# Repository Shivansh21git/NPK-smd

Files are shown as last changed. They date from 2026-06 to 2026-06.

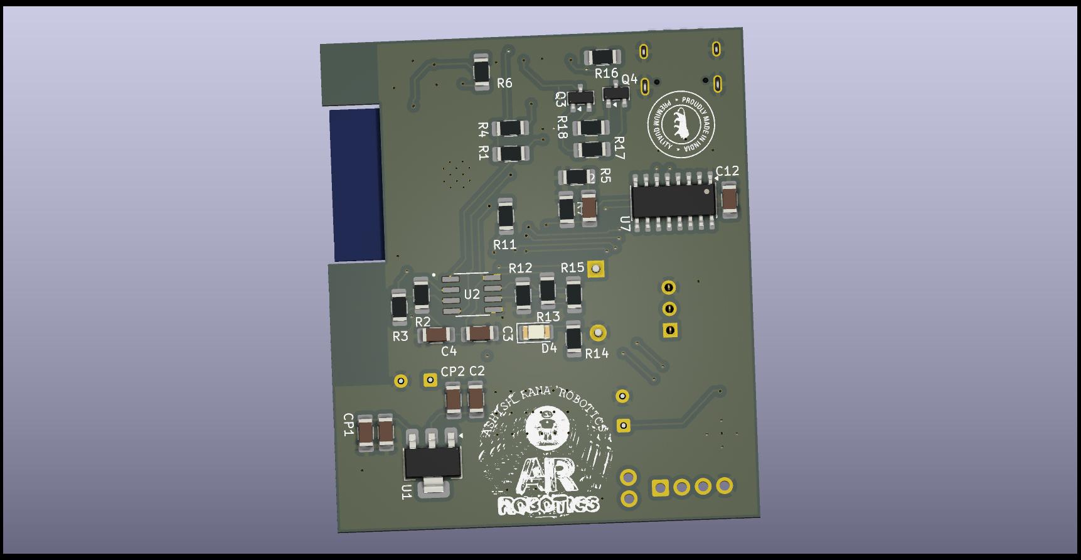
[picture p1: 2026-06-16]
images/NPK_smd_back.jpg

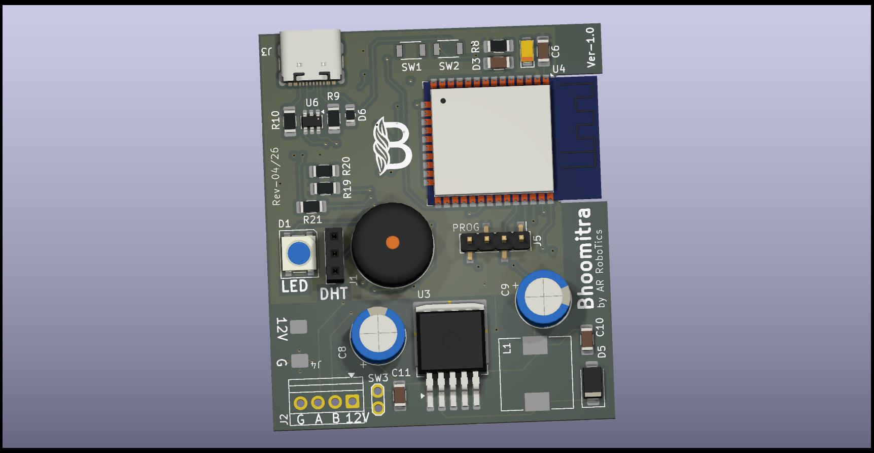
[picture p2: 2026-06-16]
images/NPK_smd_front.jpg

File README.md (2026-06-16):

# 🌱 Bhoomitra (Krishi Sarthi) – Smart NPK Soil Monitoring System

## 📌 Overview

**Bhoomitra (Krishi Sarthi)** is an embedded + IoT-based smart agriculture system designed to monitor **soil nutrient levels (NPK)** and assist farmers in making data-driven fertilization decisions.

The latest version introduces a **compact, optimized hardware architecture**, making the system more portable, robust, and suitable for real-world deployment in farms.

---

## 🎯 Problem Statement

Farmers often apply fertilizers based on guesswork, which leads to:

* Overuse of chemicals
* Increased cost
* Soil degradation
* Reduced crop yield

**Bhoomitra solves this by providing real-time soil nutrient insights.**

---

## 🧠 System Architecture

### 🔷 High-Level Architecture

```
Soil → NPK Sensor → Microcontroller → Data Processing → Output (Display / IoT)
```

### 🔷 Functional Blocks

1. **Sensing Layer**

   * NPK sensor measures Nitrogen, Phosphorus, Potassium
2. **Processing Layer**

   * Microcontroller processes raw sensor data
3. **Communication Layer (optional)**

   * Sends data to cloud / mobile app (if IoT enabled)
4. **Output Layer**

   * Displays readings or recommendations

---

## 🔌 Hardware Architecture

### 🧩 Components Used

* NPK Soil Sensor
* Microcontroller (Arduino / ESP32 / similar)
* Power Supply Module
* Display (LCD/OLED) or Serial Output
* Communication Module (WiFi / GSM – optional)

### ⚙️ Hardware Design Improvements

* ✅ Compact PCB / module layout
* ✅ Reduced wiring complexity
* ✅ Lower power consumption
* ✅ Field-ready enclosure design
* ✅ Improved durability for outdoor usage

### 🔄 Data Flow (Hardware)

1. Sensor probes inserted into soil
2. Sensor outputs analog/digital signals
3. Microcontroller reads signals via ADC/UART
4. Data is processed and calibrated
5. Output is displayed or transmitted

---

## 💻 Software Architecture

### 🧱 Software Layers

#### 1. Sensor Interface Layer

* Handles communication with NPK sensor
* Reads raw values (via UART / Analog pins)

#### 2. Data Processing Layer

* Calibration of sensor values
* Conversion into usable NPK units
* Filtering noise (basic smoothing if applied)

#### 3. Logic Layer

* Determines soil fertility status
* Can map values to:

  * Low / Medium / High nutrient levels
* Optional: fertilizer recommendation logic

#### 4. Output Layer

* Serial Monitor / LCD display
* IoT dashboard (if connected)

---

## 🔄 Working Principle

1. The NPK sensor is inserted into soil.
2. It measures nutrient concentration levels.
3. Microcontroller reads and processes the data.
4. Values are converted into meaningful units.
5. Output is shown to the user or transmitted.
6. Farmer uses insights for fertilizer planning.

---

## 🌐 IoT Integration (Optional)

* Real-time monitoring via cloud
* Data logging for analysis
* Remote farm monitoring
* Mobile-based access

---

## 📊 Example Use Case

* Farmer checks soil before sowing
* Detects low nitrogen level
* Applies only required fertilizer
* Saves cost and improves yield

---

## 🚀 Advantages

* 🌱 Promotes precision agriculture
* 💰 Reduces fertilizer waste
* 📈 Improves crop productivity
* 📦 Compact and portable design
* 🔧 Easy to deploy and maintain

---

## 🔮 Future Enhancements

* AI-based fertilizer recommendation
* Mobile app integration
* GPS-based soil mapping
* Multi-parameter sensing (pH, moisture, temperature)

---

## 📂 Repository Contents

* Embedded code
* Circuit design / hardware files
* Documentation

---

## 👨‍💻 Author

Shivansh
**Project:** Bhoomitra (Krishi Sarthi)

---

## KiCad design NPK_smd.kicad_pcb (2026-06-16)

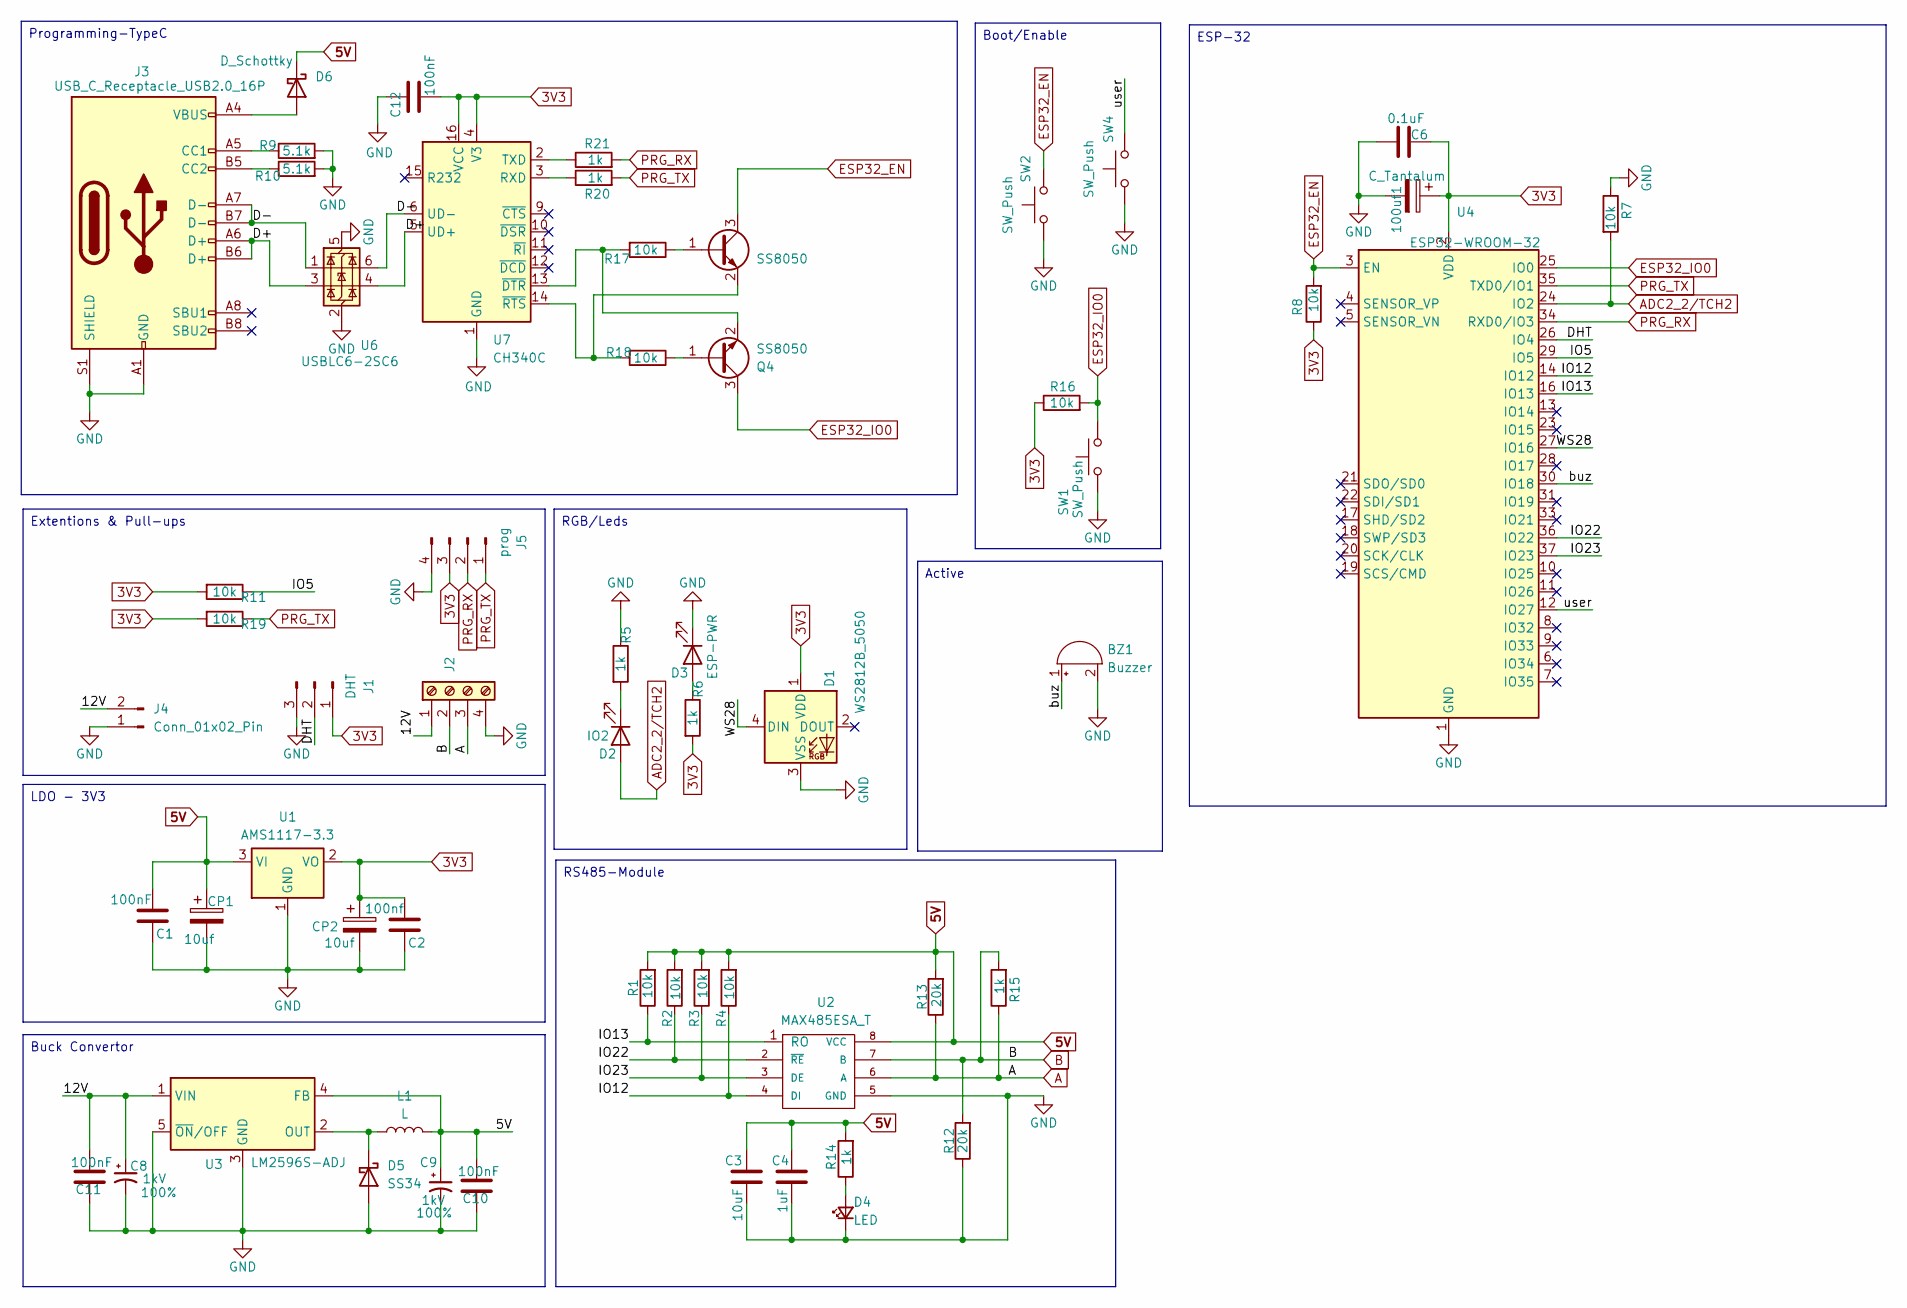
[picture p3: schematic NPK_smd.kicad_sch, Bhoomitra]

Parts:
100uf1: C_Tantalum; CP_EIA-3216-10_Kemet-I
BZ1: Buzzer; Buzzer_12x9.5RM7.6
C1, C10, C11, C12: 100nF; C_1206_3216Metric_Pad1.33x1.80mm_HandSolder
C2: 100nf; C_1206_3216Metric_Pad1.33x1.80mm_HandSolder
C3: 10uF; C_1206_3216Metric_Pad1.33x1.80mm_HandSolder
C4: 1uF; C_1206_3216Metric_Pad1.33x1.80mm_HandSolder
C6: 0.1uF; C_1206_3216Metric_Pad1.33x1.80mm_HandSolder
C8, C9: C_Polarized_Small; CP_Radial_D8.0mm_P3.50mm; Voltage 1kV; Tolerance 100%
CP1, CP2: 10uf; C_1206_3216Metric_Pad1.33x1.80mm_HandSolder
D1: WS2812B_5050; LED_WS2812B_PLCC4_5.0x5.0mm_P3.2mm
D2: IO2; C_1206_3216Metric_Pad1.33x1.80mm_HandSolder
D3: ESP-PWR; C_1206_3216Metric_Pad1.33x1.80mm_HandSolder
D4: LED; LED_1206_3216Metric
D5: SS34; D_SMA
D6: D_Schottky; R_0805_2012Metric_Pad1.20x1.40mm_HandSolder
J1: DHT; PinSocket_1x03_P2.54mm_Vertical
J2: Screw_Terminal_01x04; TerminalBlock_Xinya_XY308-2.54-4P_1x04_P2.54mm_Horizontal
J3: USB_C_Receptacle_USB2.0_16P; USB_C_Receptacle_GCT_USB4105-xx-A_16P_TopMnt_Horizontal
J4: Conn_01x02_Pin; solder-pad
J5: prog; PinHeader_1x04_P2.54mm_Vertical_SMD_Pin1Left
L1: L; L_10.4x10.4_H4.8
Q3, Q4: SS8050; SOT-23
R1, R2, R3, R4, R7, R8, R11, R16, R17, R18, R19: 10k; R_1206_3216Metric_Pad1.30x1.75mm_HandSolder
R5, R6, R14, R15, R20, R21: 1k; R_1206_3216Metric_Pad1.30x1.75mm_HandSolder
R9, R10: 5.1k; R_1206_3216Metric_Pad1.30x1.75mm_HandSolder
R12, R13: 20k; R_1206_3216Metric_Pad1.30x1.75mm_HandSolder
SW1, SW2, SW4: SW_Push; SW_B3U-1000PM
U1: AMS1117-3.3; SOT-223-3_TabPin2
U2: MAX485ESA_T; SOIC127P600X175-8N
U3: LM2596S-ADJ; TO-263-5_TabPin3
U4: ESP32-WROOM-32
U6: USBLC6-2SC6; SOT-23-6
U7: CH340C; SOIC-16_3.9x9.9mm_P1.27mm

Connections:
3V3: 100uf1.1, C2.2, C6.2, C12.2, CP2.1, D1.1 (VDD), J1.1, J5.3, R6.2, R8.1, R11.2, R16.1, R19.2, U1.2 (VO), U4.2 (VDD), U7.4 (V3), U7.16 (VCC)
5V: C1.2, C3.2, C4.2, C9.1, C10.2, CP1.1, D6.1 (K), L1.2, R1.2, R2.2, R3.2, R4.2, R13.2, R14.2, U1.3 (VI), U2.8 (VCC), U3.4 (FB)
/12V: C8.1, C11.2, J2.1, J4.2, U3.1 (VIN)
/D+: J3.A6 (D+), J3.B6 (D+), U6.3 (I/O2), U6.4 (I/O2), U7.5 (UD+)
/D-: J3.A7 (D-), J3.B7 (D-), U6.1 (I/O1), U6.6 (I/O1), U7.6 (UD-)
/DHT: J1.2, U4.26 (IO4)
/IO5: R11.1, U4.29 (IO5)
/IO12: R4.1, U2.4 (DI), U4.14 (IO12)
/IO13: R1.1, U2.1 (RO), U4.16 (IO13)
/IO22: R2.1, U2.2 (~RE), U4.36 (IO22)
/IO23: R3.1, U2.3 (DE), U4.37 (IO23)
/WS28: D1.4 (DIN), U4.27 (IO16)
/buz: BZ1.1 (+), U4.30 (IO18)
/user: SW4.2, U4.12 (IO27)
A: J2.3, R13.1, R15.1, U2.6 (A)
ADC2_2/TCH2: D2.2 (A), R7.2, U4.24 (IO2)
B: J2.2, R12.2, R15.2, U2.7 (B)
ESP32_EN: Q3.3 (C), R8.2, SW2.2, U4.3 (EN)
ESP32_IO0: Q4.3 (C), R16.2, SW1.2, U4.25 (IO0)
GND: 100uf1.2, BZ1.2 (-), C1.1, C2.1, C3.1, C4.1, C6.1, C8.2, C9.2, C10.1, C11.1, C12.1, CP1.2, CP2.2, D1.3 (VSS), D3.1 (K), D4.1 (K), D5.2 (A), J1.3, J2.4, J3.A1 (GND), J3.A12 (GND), J3.B1 (GND), J3.B12 (GND), J3.S1 (SHIELD), J4.1, J5.4, R5.1, R7.1, R9.2, R10.2, R12.1, SW1.1, SW2.1, SW4.1, U1.1 (GND), U2.5 (GND), U3.3 (GND), U3.5 (~ON/OFF), U4.1 (GND), U4.15 (GND), U4.38 (GND), U4.39 (GND), U6.2 (GND), U6.5 (VBUS), U7.1 (GND)
unnamed: D2.1 (K), R5.2
unnamed: D3.2 (A), R6.1
unnamed: D4.2 (A), R14.1
unnamed: D5.1 (K), L1.1, U3.2 (OUT)
unnamed: D6.2 (A), J3.A4 (VBUS), J3.A9 (VBUS), J3.B4 (VBUS), J3.B9 (VBUS)
unnamed: J3.A5 (CC1), R9.1
unnamed: J3.B5 (CC2), R10.1
unnamed: Q3.1 (B), R17.1
unnamed: Q3.2 (E), R18.2, U7.14 (~RTS)
unnamed: Q4.1 (B), R18.1
unnamed: Q4.2 (E), R17.2, U7.13 (~DTR)
unnamed: R20.1, U7.3 (RXD)
unnamed: R21.1, U7.2 (TXD)
PRG_RX: J5.2, R21.2, U4.34 (RXD0/IO3)
PRG_TX: J5.1, R19.1, R20.2, U4.35 (TXD0/IO1)

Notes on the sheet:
Boot/Enable
Buck Convertor
Extentions & Pull-ups
ESP-32
Active
RS485-Module
RGB/Leds
Programming-TypeC
LDO - 3V3

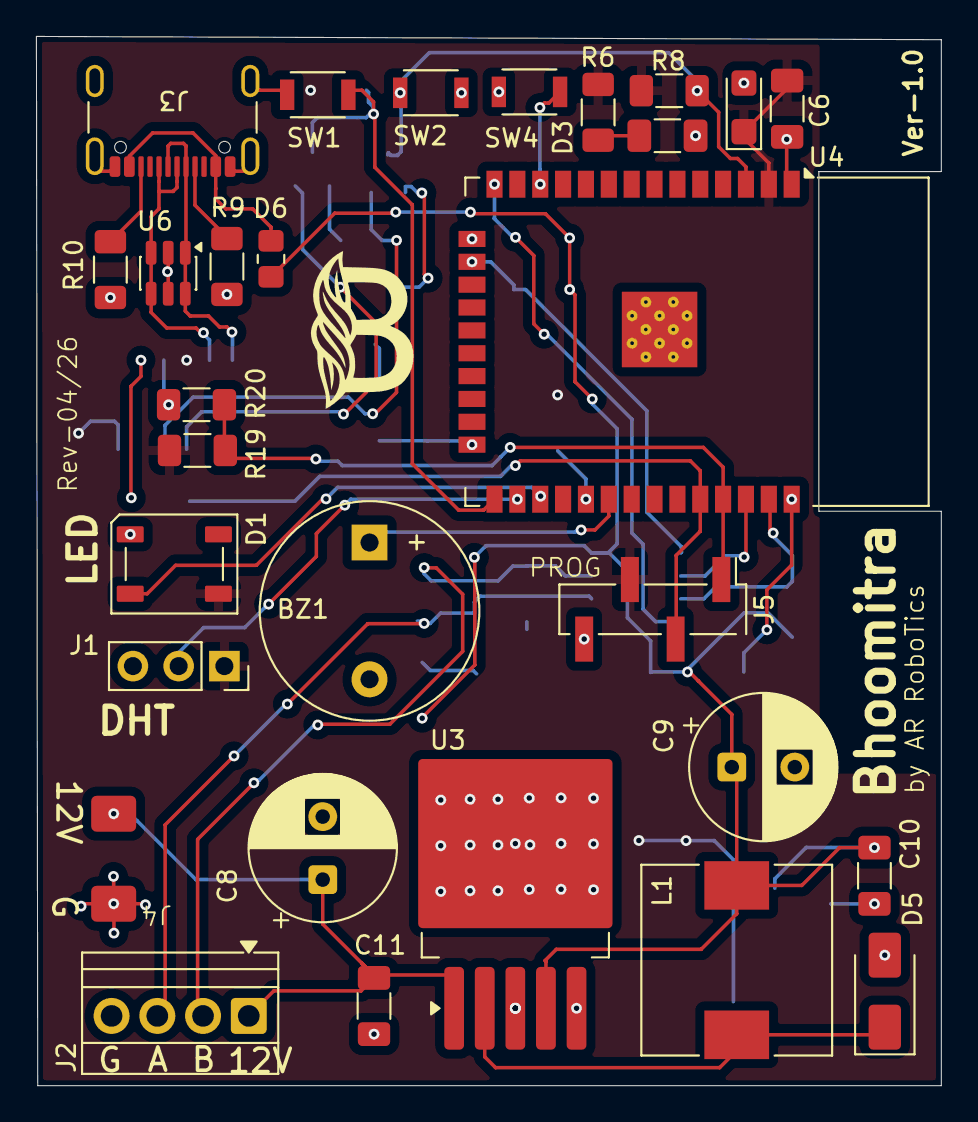
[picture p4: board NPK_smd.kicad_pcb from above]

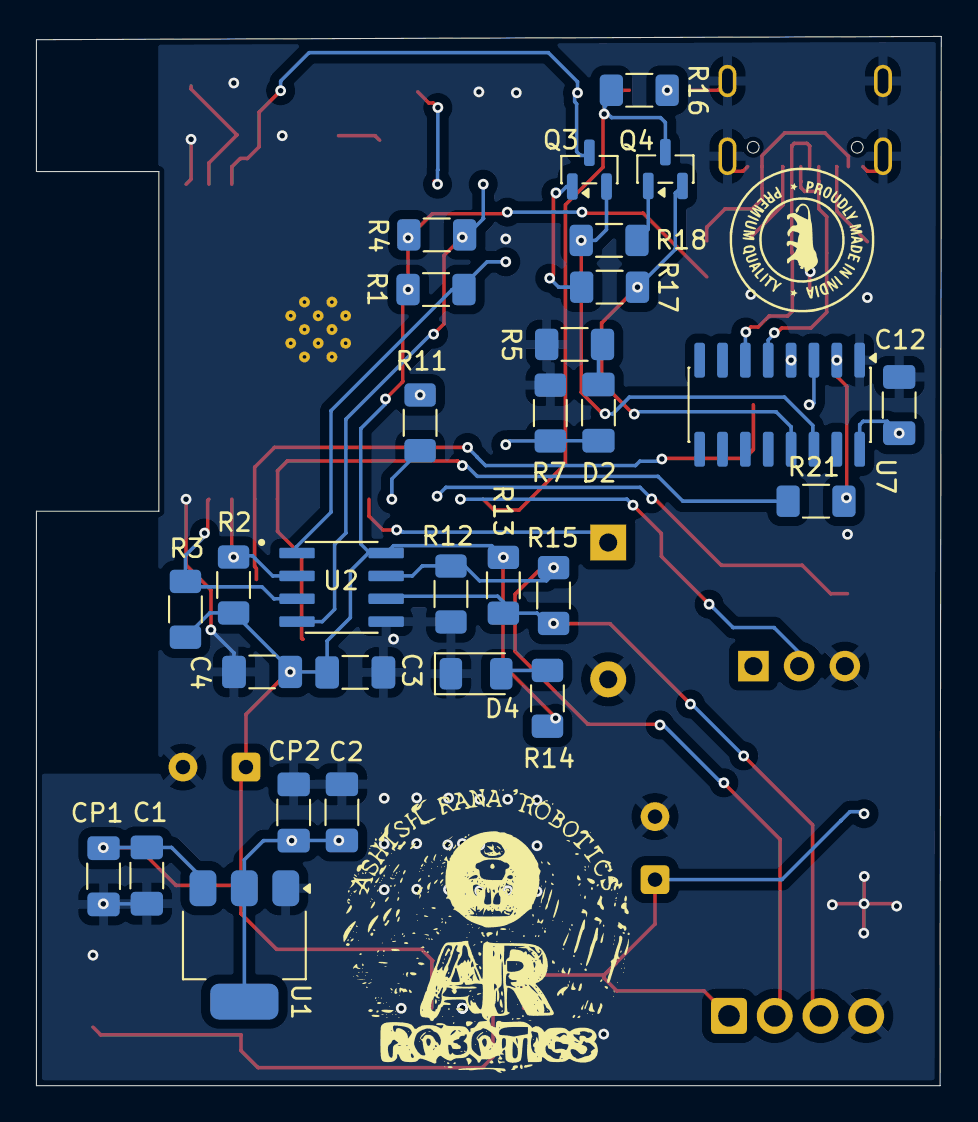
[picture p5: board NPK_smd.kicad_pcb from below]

Board: 2 copper layers, 50.3 x 58.3 mm, 58 parts (29 on the bottom side), 35 nets.

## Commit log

2026-03-13 NPK-smd version initial commit
    [NPK_smd.kicad_pcb, NPK_smd.kicad_sch]
2026-06-16 size minimizations and updations
    [NPK_smd.kicad_pcb, NPK_smd.kicad_sch]
2026-06-16 version-1.0 rev 2026-04-11
    [NPK_smd.kicad_pcb, NPK_smd.kicad_sch]
